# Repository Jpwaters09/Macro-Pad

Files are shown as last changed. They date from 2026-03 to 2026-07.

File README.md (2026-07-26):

# Macro Pad

A 12-key macro pad with a configurable rotary encoder and OLED display, built around the RP2354A microcontroller and custom MicroPython firmware. Fully programmable through a web-based configurator.

##

<div style="display: flex">
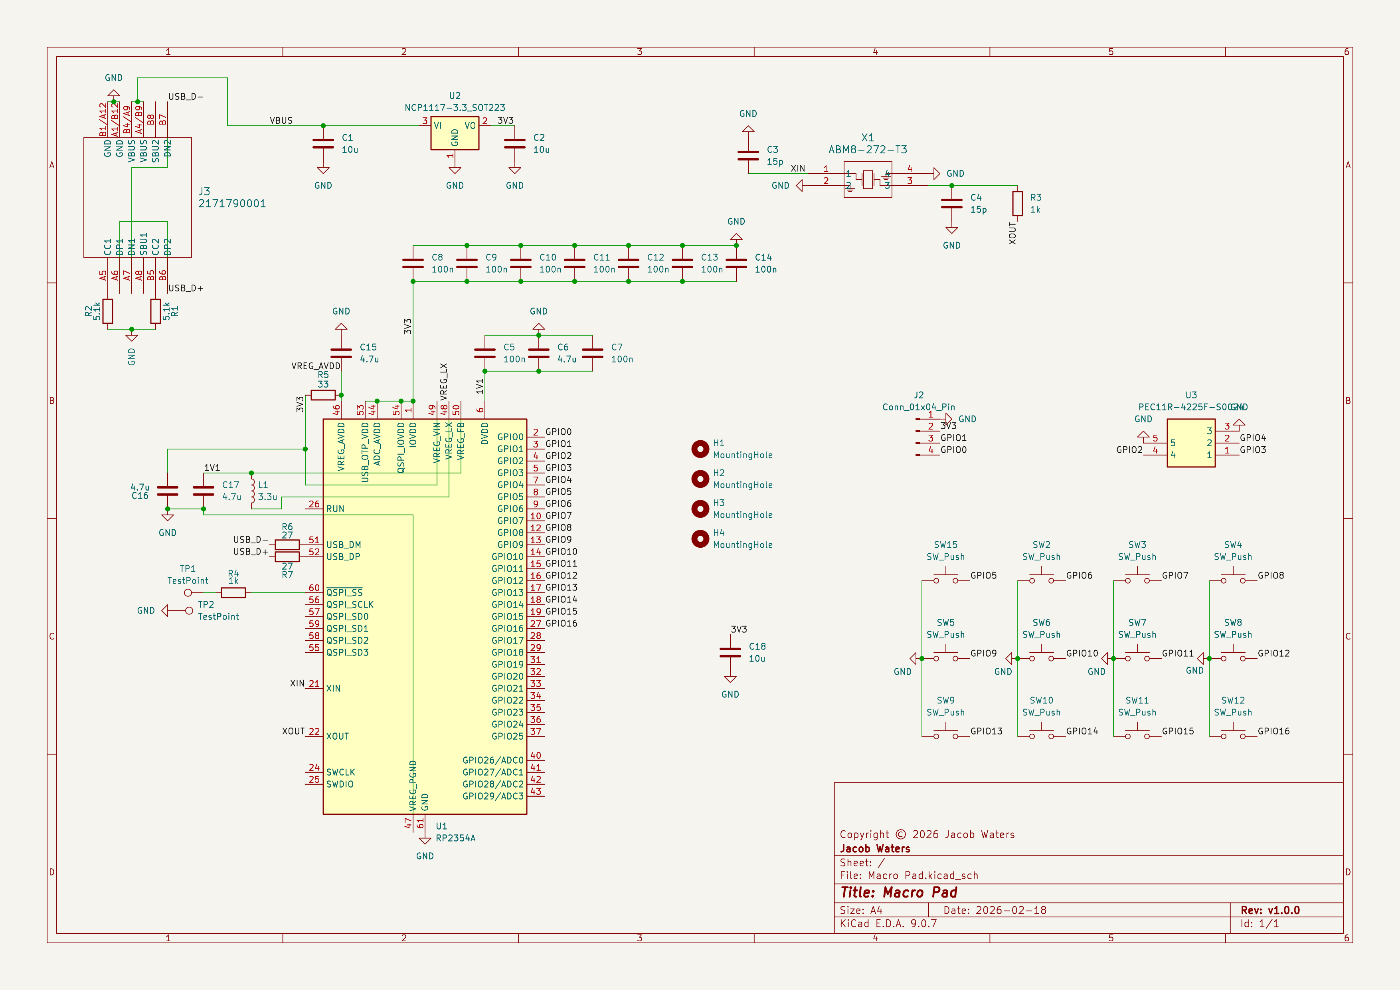
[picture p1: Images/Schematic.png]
  
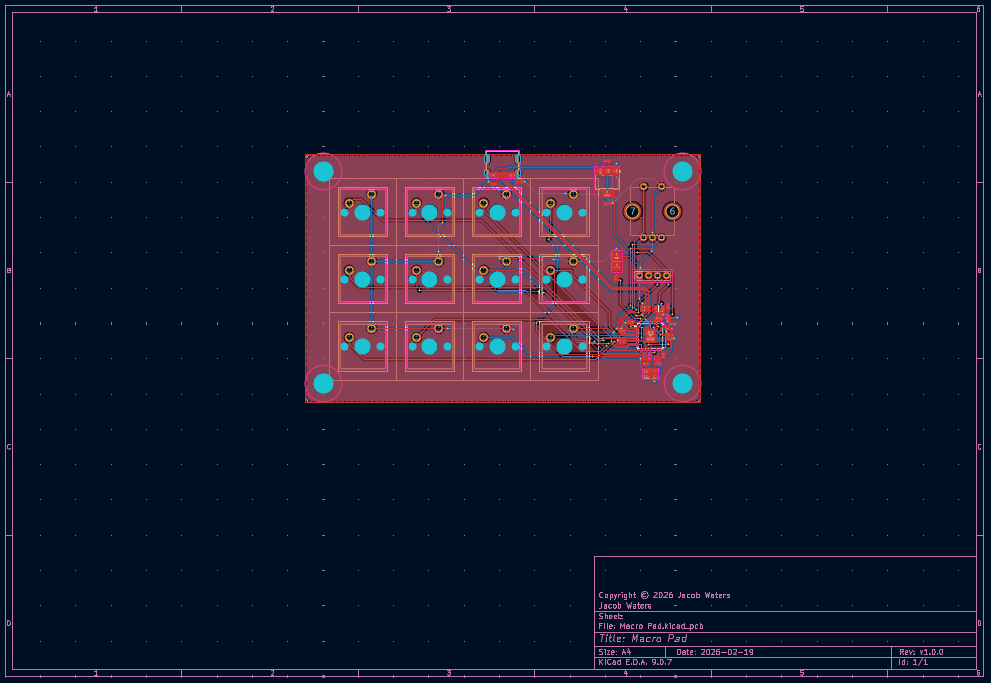
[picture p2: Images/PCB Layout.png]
  
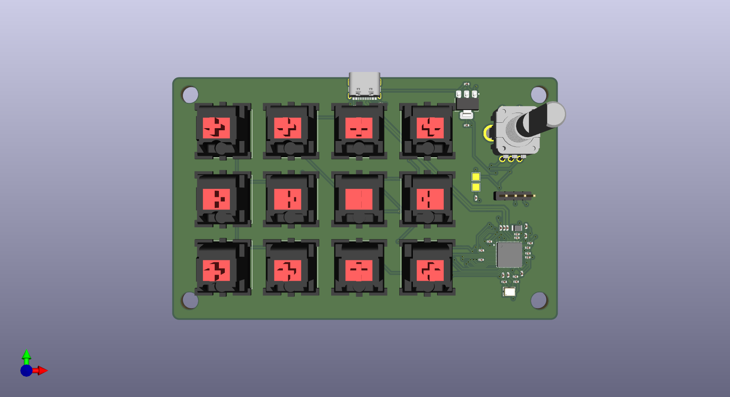
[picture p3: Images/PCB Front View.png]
  
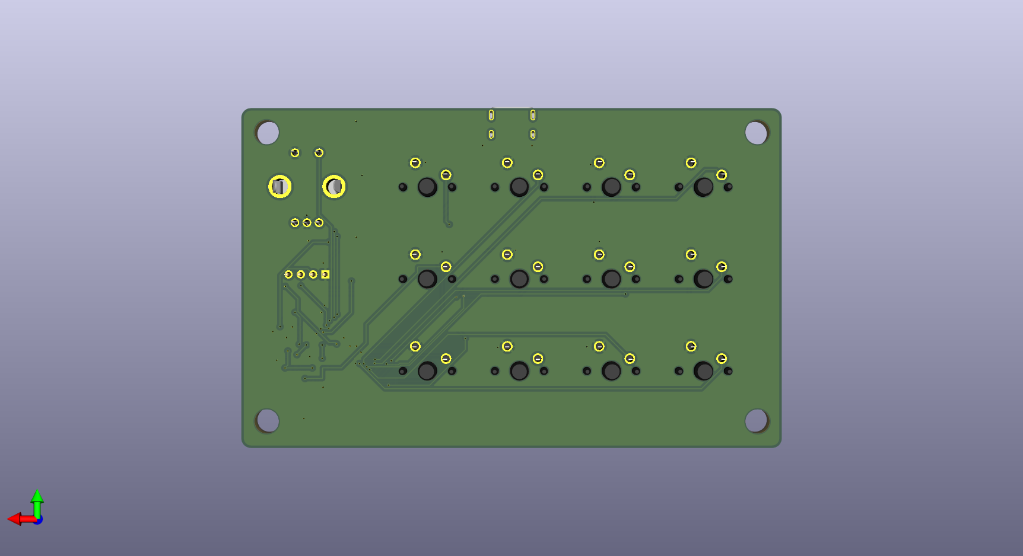
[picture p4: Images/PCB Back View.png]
  
  
  
</div>

##

## How to Use
Plug the Macro Pad into your Windows, Linux, or macOS device using a USB-C data cable, then go to the [Installation Website](https://macropad.jpwaters09.com/Install%20or%20Update) and follow the steps to install (or update) the Macro Pad firmware. This requires a browser that supports Web Serial (Chrome, Edge, Opera, or Firefox), Safari isn't supported.

The OLED display shows the current layer and the function assigned to each key. Press and hold the rotary encoder button to switch layers.

To configure the device (adding, editing, or deleting layers) visit the [Macro Pad Programmer](https://macropad.jpwaters09.com/Configurator).

## Coming Soon
 - A Windows app that will allow you to update and configure settings for the Macro Pad.

## Why I Made This
I built this project to create a fully customisable and open-sourced macro pad. It has also served as a way to develop my skills in schematic design, PCB layout, and 3D Modelling.

## Features
 - USB C
 - 12 macro buttons
 - Rotary encoder with button
 - 128 x 64 OLED display
 - 3D printable housing
 - RP2354A microcontroller
 - 2MB internal flash storage
 - Custom Micropython firmware
 - Multiple programmable layers
 - Web-based configurator (no software install)
 - USB HID compliant (works instantly on any OS)

## Bill Of Materials
|Item |Description |Quantity|Unit Price (£)|Total Price (£) Inc. Tax|URL |
|---|---|---|---|---|---|
|CL05A104KA5NNNC |100nF ±10% 25V Ceramic Capacitor X5R 0402 |100 |$0.0016 |$0.16 |https://www.lcsc.com/product-detail/C100072.html |
|CC0402KRX5R5BB103 |10nF ±10% 6.3V Ceramic Capacitor X5R 0402 |100 |$0.0012 |$0.12 |https://www.lcsc.com/product-detail/C1853984.html |
|HGC0805R7106K250NSLJ  |10uF ±10% 25V Ceramic Capacitor X7R 0805 |5 |$0.1585 |$0.79 |https://www.lcsc.com/product-detail/C33546010.html |
|ABM8-272-T3 |±30ppm 10pF ±30ppm SMD3225-4P Crystals RoHS |5 |$0.2902 |$1.45 |https://www.lcsc.com/product-detail/C20625731.html |
|CL05C150JB5NNNC |15pF ±5% 50V Ceramic Capacitor C0G 0402 |100 |$0.0036 |$0.36 |https://www.lcsc.com/product-detail/C86285.html |
|FRC0402J102 TS |1kΩ 62.5mW 50V Thick Film Resistor ±100ppm/℃ ±5% 0402 Chip Resistor |100 |$0.0008 |$0.08 |https://www.lcsc.com/product-detail/C2906899.html |
|RC0402FR-0727RL |27Ω ±1% 62.5mW 0402 Thick Film Resistor |100 |$0.0008 |$0.08 |https://www.lcsc.com/product-detail/C138021.html |
|AOTA-B201610S3R3-101-T|2.1A 3.3uH 115mΩ 2.4A Molded Inductor 0806 Fixed Inductors RoHS |5 |$0.2888 |$1.44 |https://www.lcsc.com/product-detail/C42411119.html |
|RAT0233R0FTH |62.5mW 33Ω 50V Thick Film Resistor ±100ppm/℃ ±1% 0402 Chip Resistor |100 |$0.0015 |$0.15 |https://www.lcsc.com/product-detail/C5139599.html |
|CL05A475KQ5NRNC |4.7uF ±10% 6.3V Ceramic Capacitor X5R 0402 |100 |$0.0060 |$0.60 |https://www.lcsc.com/product-detail/C2932473.html |
|1RC0402F5101 |5.1kΩ ±1% 62.5mW 0402 Thick Film Resistor |100 |$0.0009 |$0.09 |https://www.lcsc.com/product-detail/C53224182.html |
|NCP1117ST33T3G |Linear Voltage Regulator IC Positive Fixed 1 Output 1A SOT-223 |5 |$0.2615 |$1.31 |https://www.lcsc.com/product-detail/C26537.html |
|PZ254V-11-04P |Pin Header 4 Position 2.54mm Pitch Single Row Through Hole -40℃~+105℃|20 |$0.0236 |$0.47 |https://www.lcsc.com/product-detail/C2691448.html |
|Rotary Encoder Knob |22x12mm 6mm D-Type Shaft Hole Knob |1 |$1.6500 |$1.65 |https://www.aliexpress.com/item/1005011592374989.html|
|SSD1306 |128x64 I2C OLED Display |1 |$0.9900 |$0.99 |https://www.aliexpress.com/item/1005008995931139.html|
|PEC11R-4225F-S0024 |Plugin Encoders RoHS |1 |$1.8539 |$1.85 |https://www.lcsc.com/product-detail/C18198884.html |
|Cherry MX Keycaps |Blank black keycap for Cherry MX switches |20 |$0.1500 |$3.00 |https://www.aliexpress.com/item/1005007572331245.html|
|Cherry MX Red Switch  |Cherry MX red 3-pin linear switches |16 |$0.65 |$10.43 |https://www.aliexpress.com/item/4000100166477.html |
|RP2354A |QFN-60(7x7) Microcontrollers RoHS |1 |$1.4615 |$1.46 |https://www.lcsc.com/product-detail/C41378174.html |
|2171790001 |USB 2.0 5A 1 16P -40℃~+85℃ SMD USB Connector Assemblies RoHS |1 |$0.6229 |$0.62 |https://www.lcsc.com/product-detail/C3197684.html |

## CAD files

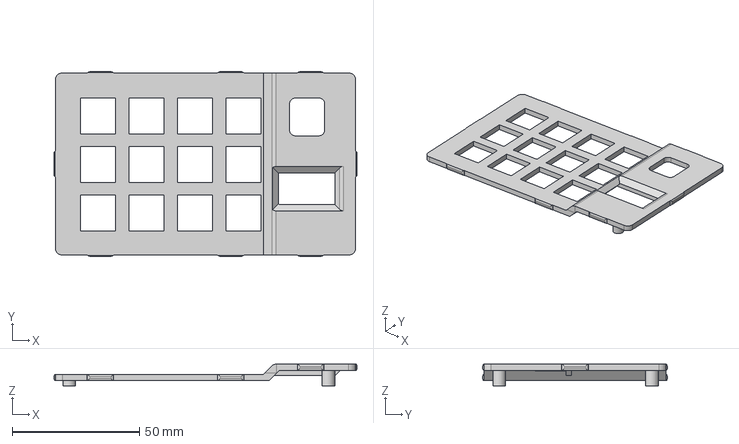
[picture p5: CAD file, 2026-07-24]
CAD Files/Macro Pad Top.step
119.0 x 72.5 x 8.51 mm

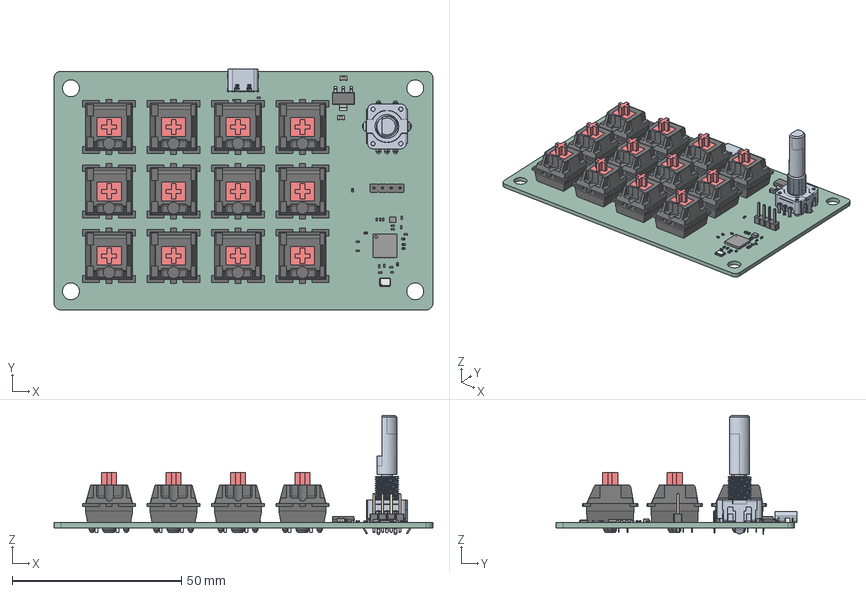
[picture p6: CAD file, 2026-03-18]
PCB Files/Macro Pad.step
112.0 x 71.2 x 35.2 mm
C_0402_1005Metric x 23
C_0805_2012Metric x 2
ThermalPin
PinsArrayLR
PinsArrayTB
SOT-223
PinHeader_1x04_P2.54mm_Vertical
ABM8-272-T3
PEC11R-4225F-S0024
AOTA-B201610S3R3-101-T
Macro Pad_PCB

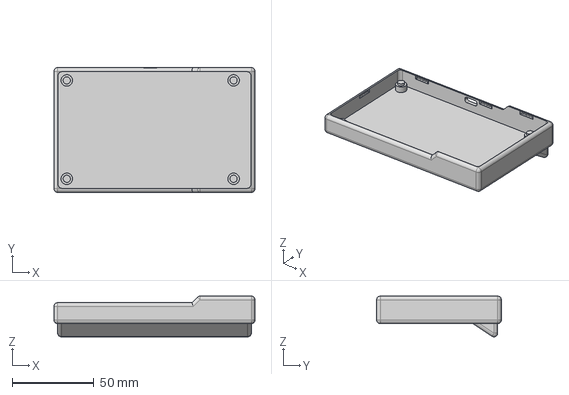
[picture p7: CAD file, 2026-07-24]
CAD Files/Macro Pad Bottom.step
122.6 x 76.1 x 24.9 mm

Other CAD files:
CAD Files/Macro Pad Bottom.stl
CAD Files/Macro Pad Top.stl
CAD Files/Macro Pad.f3z

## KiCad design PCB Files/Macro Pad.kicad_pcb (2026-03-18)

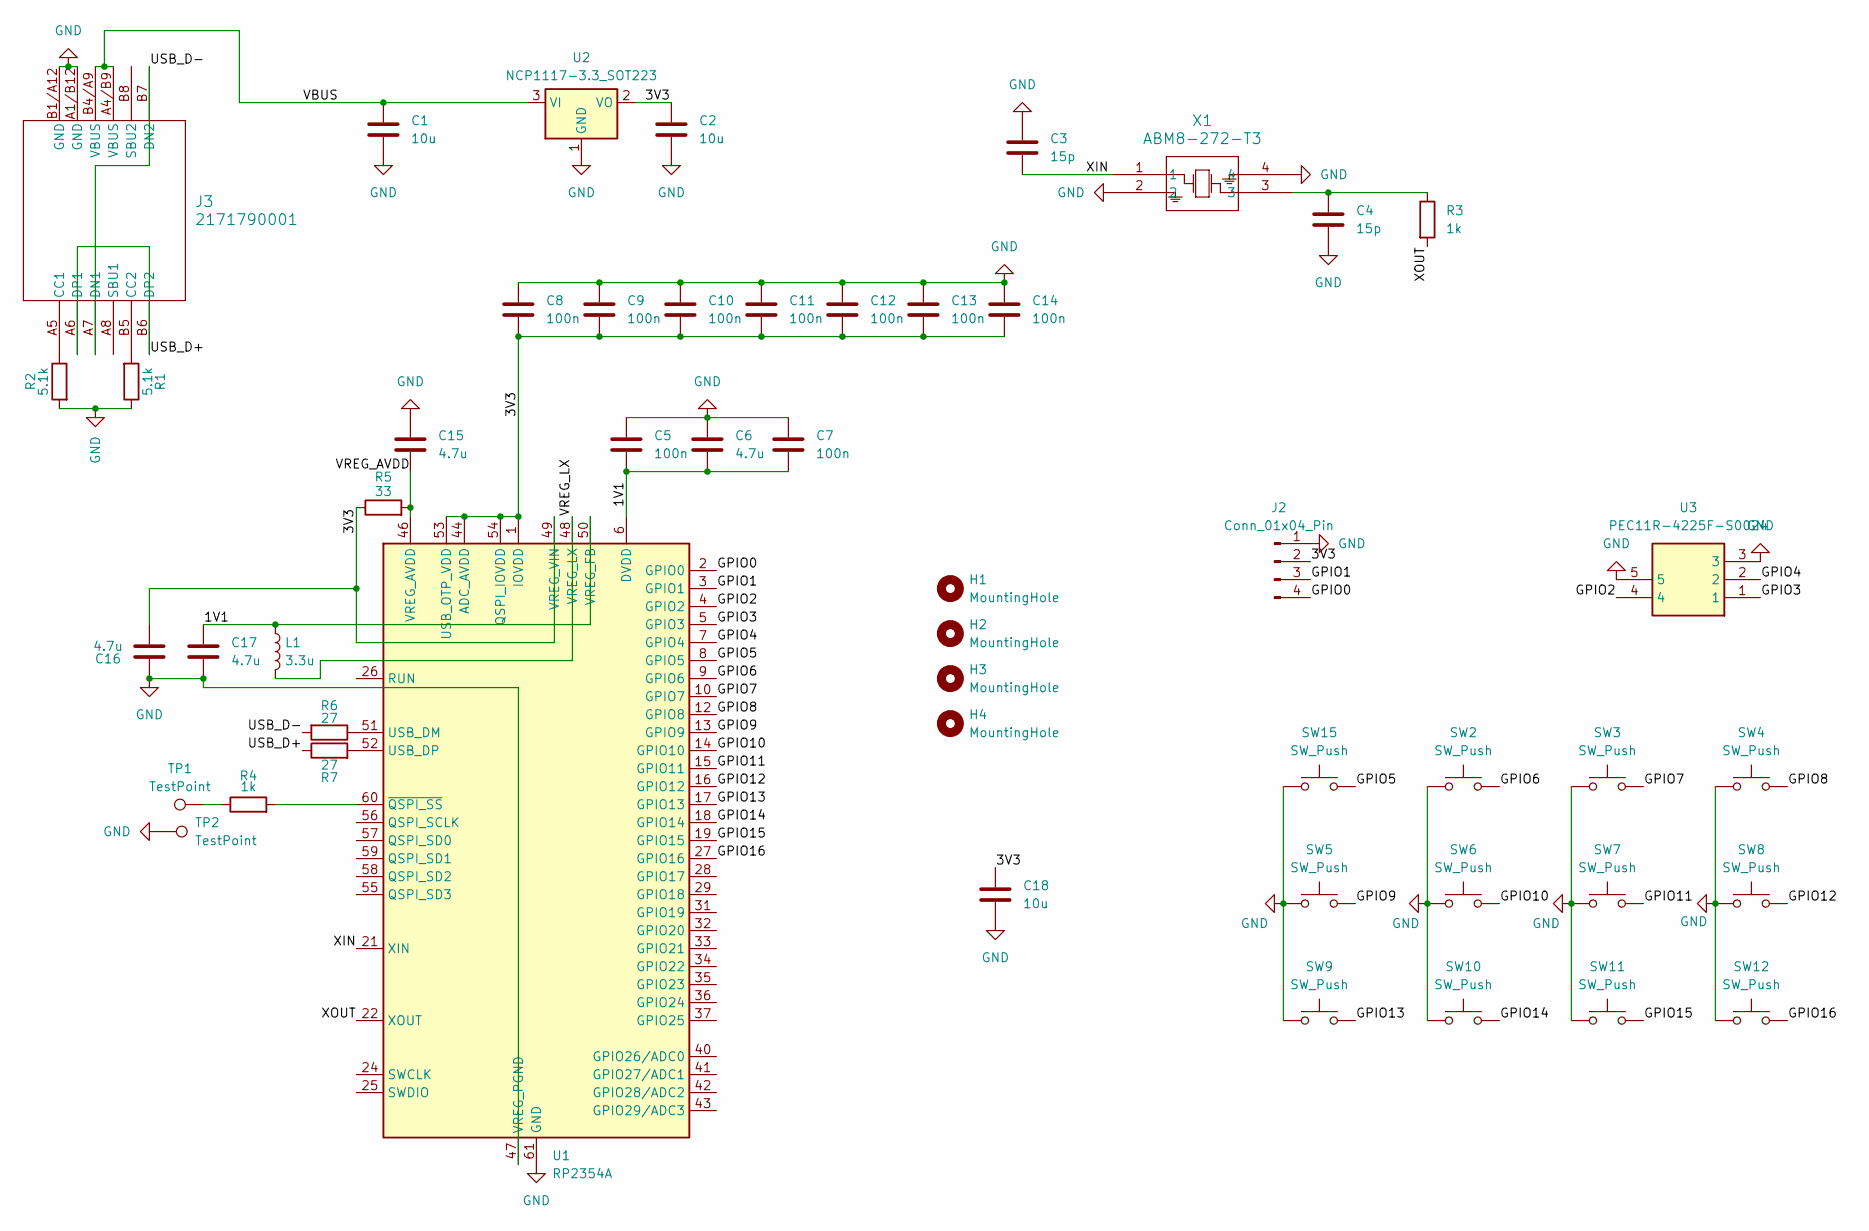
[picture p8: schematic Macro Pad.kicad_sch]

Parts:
C1, C2: 10u; C_0805_2012Metric
C3, C4: 15p; C_0402_1005Metric
C5, C7, C8, C9, C10, C11, C12, C13, C14: 100n; C_0402_1005Metric
C6, C15, C16, C17: 4.7u; C_0402_1005Metric
C18: 10u; C_0402_1005Metric
H1, H2, H3, H4: MountingHole; MountingHole_5mm
J2: Conn_01x04_Pin; PinHeader_1x04_P2.54mm_Vertical
J3: 2171790001; 2171790001_MOL
L1: 3.3u; AOTAB201610S3R3101T
R1, R2: 5.1k; C_0402_1005Metric
R3, R4: 1k; C_0402_1005Metric
R5: 33; C_0402_1005Metric
R6, R7: 27; C_0402_1005Metric
SW2, SW3, SW4, SW5, SW6, SW7, SW8, SW9, SW10, SW11, SW12, SW15: SW_Push; SW_Cherry_MX_1.00u_PCB
TP1, TP2: TestPoint; TestPoint_Pad_2.0x2.0mm
U1: RP2354A; QFN-60-1EP_7x7mm_P0.4mm_EP3.4x3.4mm
U2: NCP1117-3.3_SOT223; SOT-223-3_TabPin2
U3: PEC11R-4225F-S0024; Manufacturer_Part_Number PEC11R-4225F-S0024; Mouser Part Number 652-PEC11R-4225F-S24
X1: ABM8-272-T3; ABM8-272-T3_ABR

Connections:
/1V1: C5.2, C6.2, C7.2, C17.1, L1.1, U1.6 (DVDD), U1.23 (DVDD), U1.39 (DVDD), U1.50 (VREG_FB)
/3V3: C2.1, C8.2, C9.2, C10.2, C11.2, C12.2, C13.2, C14.2, C16.2, C18.1, J2.2, R5.1, U1.1 (IOVDD), U1.11 (IOVDD), U1.20 (IOVDD), U1.30 (IOVDD), U1.38 (IOVDD), U1.44 (ADC_AVDD), U1.45 (IOVDD), U1.49 (VREG_VIN), U1.53 (USB_OTP_VDD), U1.54 (QSPI_IOVDD), U2.2 (VO)
/GPIO0: J2.4, U1.2 (GPIO0)
/GPIO1: J2.3, U1.3 (GPIO1)
/GPIO2: U1.4 (GPIO2), U3.4
/GPIO3: U1.5 (GPIO3), U3.1
/GPIO4: U1.7 (GPIO4), U3.2
/GPIO5: SW15.2, U1.8 (GPIO5)
/GPIO6: SW2.2, U1.9 (GPIO6)
/GPIO7: SW3.2, U1.10 (GPIO7)
/GPIO8: SW4.2, U1.12 (GPIO8)
/GPIO9: SW5.2, U1.13 (GPIO9)
/GPIO10: SW6.2, U1.14 (GPIO10)
/GPIO11: SW7.2, U1.15 (GPIO11)
/GPIO12: SW8.2, U1.16 (GPIO12)
/GPIO13: SW9.2, U1.17 (GPIO13)
/GPIO14: SW10.2, U1.18 (GPIO14)
/GPIO15: SW11.2, U1.19 (GPIO15)
/GPIO16: SW12.2, U1.27 (GPIO16)
/USB_D+: J3.A6 (DP1), J3.B6 (DP2), R7.1
/USB_D-: J3.A7 (DN1), J3.B7 (DN2), R6.2
/VBUS: C1.1, J3.A4/B9 (VBUS), J3.B4/A9 (VBUS), U2.3 (VI)
/VREG_AVDD: C15.2, R5.2, U1.46 (VREG_AVDD)
/VREG_LX: L1.2, U1.48 (VREG_LX)
/XIN: C3.1, U1.21 (XIN), X1.1
/XOUT: R3.2, U1.22 (XOUT)
GND: C1.2, C2.2, C3.2, C4.2, C5.1, C6.1, C7.1, C8.1, C9.1, C10.1, C11.1, C12.1, C13.1, C14.1, C15.1, C16.1, C17.2, C18.2, J2.1, J3.A1/B12 (GND), J3.B1/A12 (GND), R1.1, R2.2, SW2.1, SW3.1, SW4.1, SW5.1, SW6.1, SW7.1, SW8.1, SW9.1, SW10.1, SW11.1, SW12.1, SW15.1, TP2.1, U1.47 (VREG_PGND), U1.61 (GND), U2.1 (GND), U3.3, U3.5, X1.2, X1.4
unnamed: C4.1, R3.1, X1.3
unnamed: J3.A5 (CC1), R2.1
unnamed: J3.B5 (CC2), R1.2
unnamed: R4.1, TP1.1
unnamed: R6.1, U1.51 (USB_DM)
unnamed: R7.2, U1.52 (USB_DP)
unnamed: R4.2, U1.60 (~QSPI_SS)

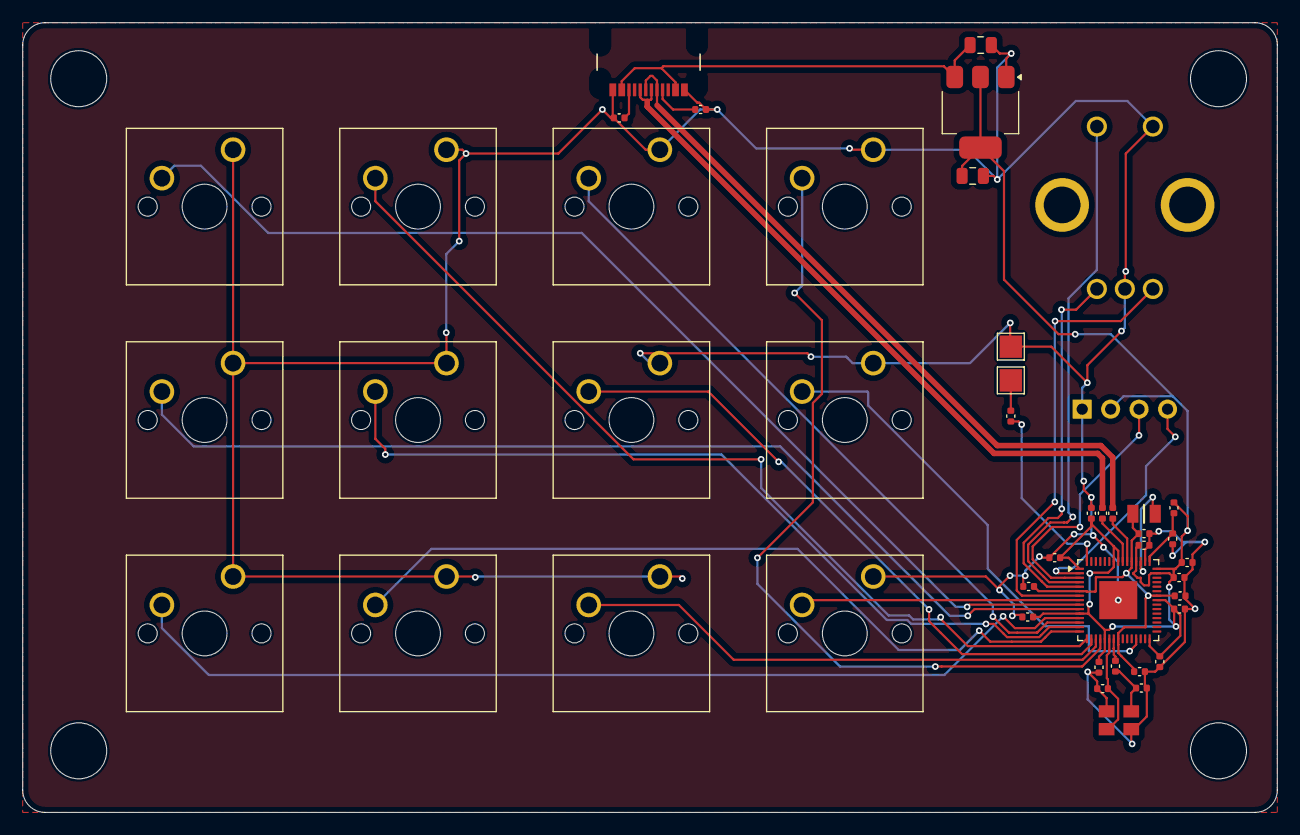
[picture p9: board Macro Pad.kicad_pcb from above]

Board: 2 copper layers, 112.0 x 70.5 mm, 50 parts (0 on the bottom side), 34 nets.

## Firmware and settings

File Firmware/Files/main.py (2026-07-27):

from machine import Pin, I2C
import ssd1306
from time import sleep
import time
from screens import *
from displayFunctions import *
import usb.device
from usb.device.keyboard import KeyboardInterface
from usb.device.mouse import MouseInterface
import _thread
from consumer import ConsumerInterface
import json
import sys
import os

with open("config.json", "r") as file:
    data = json.load(file)

    activated = data["Activated"]

    serialNumber = data["Serial Number"]

    softwareVersion = data["Software Version"]
    
    sleepTime = data["Sleep Time"]

hardwareVersionMajor, hardwareVersionMinor, hardwareVersionMicro = map(int, "v1.0.0".lstrip("v").split("."))
hardwareVersionBcd = (hardwareVersionMajor << 8) | (hardwareVersionMinor << 4) | hardwareVersionMicro

keyboard = KeyboardInterface()
mouse = MouseInterface()
consumer = ConsumerInterface()

i2c = I2C(sda=Pin("OLED_SDA"), scl=Pin("OLED_SCL"))
display = ssd1306.SSD1306_I2C(128, 64, i2c)

macroButtonPins = ["ENCODER_BTN",
                   "BTN_1", "BTN_2", "BTN_3", "BTN_4",
                   "BTN_5", "BTN_6", "BTN_7", "BTN_8",
                   "BTN_9", "BTN_10", "BTN_11", "BTN_12"]

macroButtons = []

for pin in macroButtonPins:
    macroButtons.append(Pin(pin, Pin.IN, Pin.PULL_UP))

display.contrast(0)

if activated or serialNumber:
    usb.device.get().init(keyboard,
                          consumer,
                          mouse,
                          builtin_driver=True,
                          manufacturer_str="Jacob Waters",
                          product_str="Macro Pad",
                          serial_str=serialNumber,
                          id_vendor=4617,
                          id_product=31291,
                          bcd_device=hardwareVersionBcd)

startUpScreen(display, softwareVersion)
increaseBrightness(display, speed=0.02)

if not activated or not serialNumber:
    notActivatedScreen(display)
    
    while True:
        pass

layers = len(os.listdir("/Layers"))

if layers == 0:
    noLayersScreen(display)
    
    while True:
        pass

loadedLayers = {}

for layer in range(1, layers + 1):
    sys.path.append(f"/Layers/{layer}/")
    layerMod = __import__(f"Layer{layer}")
    keysMod = __import__(f"Keys{layer}")
    
    loadedLayers[layer] = {
        "layer": layerMod,
        "keys": keysMod,
    }

currentLayer = 1

display.fill(0)

loadedLayers[currentLayer]["layer"].layer(display)

last_press = time.ticks_ms()
lock = _thread.allocate_lock()
displayBrightnessLowered = False
displaySleep = False

R_START     = 0x0
R_CW_FINAL  = 0x1
R_CW_BEGIN  = 0x2
R_CW_NEXT   = 0x3
R_CCW_BEGIN = 0x4
R_CCW_FINAL = 0x5
R_CCW_NEXT  = 0x6

DIR_CW  = 0x10
DIR_CCW = 0x20

ttable = (
    (R_START,    R_CW_BEGIN,  R_CCW_BEGIN, R_START),
    (R_CW_NEXT,  R_START,     R_CW_FINAL,  R_START | DIR_CW),
    (R_CW_NEXT,  R_CW_BEGIN,  R_START,     R_START),
    (R_CW_NEXT,  R_CW_BEGIN,  R_CW_FINAL,  R_START),
    (R_CCW_NEXT, R_START,     R_CCW_BEGIN, R_START),
    (R_CCW_NEXT, R_CCW_FINAL, R_START,     R_START | DIR_CCW),
    (R_CCW_NEXT, R_CCW_FINAL, R_CCW_BEGIN, R_START),
)

encoderA = Pin("ENCODER_A", Pin.IN, Pin.PULL_UP)
encoderB = Pin("ENCODER_B", Pin.IN, Pin.PULL_UP)

encoder_state   = R_START
encoder_delta   = 0
encoder_velocity = 0.0
last_encoder_ms = time.ticks_ms()

def encoder_handler(pin):
    global encoder_state, encoder_delta, last_press

    pinstate = (encoderA.value() << 1) | encoderB.value()
    encoder_state = ttable[encoder_state & 0x0F][pinstate]
    direction = encoder_state & 0x30

    if direction == DIR_CW:
        encoder_delta += 1
        
    elif direction == DIR_CCW:
        encoder_delta -= 1

    if direction:
        with lock:
            last_press = time.ticks_ms()

encoderA.irq(trigger=Pin.IRQ_FALLING | Pin.IRQ_RISING, handler=encoder_handler)
encoderB.irq(trigger=Pin.IRQ_FALLING | Pin.IRQ_RISING, handler=encoder_handler)

stopIdleWatcher = False

def idleWatcher():
    global last_press, displayBrightnessLowered, displaySleep

    while not stopIdleWatcher:
        with lock:
            elapsed = time.ticks_diff(time.ticks_ms(), last_press)

        if elapsed >= sleepTime:
            if not displayBrightnessLowered:
                decreaseBrightness(display)
                displayBrightnessLowered = True

            elif not displaySleep:
                display.poweroff()
                displaySleep = True

            with lock:
                last_press = time.ticks_ms()
                
        time.sleep_ms(500)
        
def encoderLongPress():
    global currentLayer
    
    if layers > 1:        
        if currentLayer != layers:
            currentLayer += 1
            display.fill(0)
            loadedLayers[currentLayer]["layer"].layer(display)
            
        else:
            currentLayer = 1
            display.fill(0)
            loadedLayers[currentLayer]["layer"].layer(display)
            
_thread.start_new_thread(idleWatcher, ())

prev = [not btn.value() for btn in macroButtons]

pressStartTimes = [None] * len(macroButtons)
nextRepeatTime  = [None] * len(macroButtons)

encoderPressStart = None
encoderLongPressFired = False
encoder_last_dir = 0
encoder_dir_lock_until = 0

while True:
    now = time.ticks_ms()
    dt = time.ticks_diff(now, last_encoder_ms) / 1000.0
    last_encoder_ms = now

    encoder_velocity *= max(0.0, 1.0 - (dt * 7.5))

    if encoder_delta != 0:
        raw = encoder_delta
        encoder_delta = 0

        current_dir = 1 if raw > 0 else -1
        if current_dir != encoder_last_dir and time.ticks_diff(now, encoder_dir_lock_until) < 0:
            raw = 0
            
        else:
            encoder_last_dir = current_dir
            
            if abs(encoder_velocity) > 3.0:
                encoder_dir_lock_until = time.ticks_add(now, 40)

        if raw != 0:
            encoder_velocity += raw * 1.2

            if encoder_velocity > 10:
                encoder_velocity = 10.0
            elif encoder_velocity < -10:
                encoder_velocity = -10.0

    steps = int(round(encoder_velocity))

    if abs(steps) >= 2 and abs(encoder_velocity) < 1.7:
        steps = 1 if encoder_velocity > 0 else -1

    if steps != 0:
        encoder_velocity *= 0.55

        if displaySleep:
            displaySleep = False
            displayBrightnessLowered = False
            display.poweron()
            increaseBrightness(display)
            
        elif displayBrightnessLowered:
            displayBrightnessLowered = False
            increaseBrightness(display)
            
        loadedLayers[currentLayer]["keys"].rotaryChecker(keyboard, consumer, mouse, steps)

    for i, btn in enumerate(macroButtons):
        pressed = not btn.value()
        
        if i == 0:
            if pressed and not prev[i]:
                encoderPressStart = time.ticks_ms()
                encoderLongPressFired = False

                if displaySleep:
                    displaySleep = False
                    displayBrightnessLowered = False
                    display.poweron()
                    increaseBrightness(display)
                    
                elif displayBrightnessLowered:
                    displayBrightnessLowered = False
                    increaseBrightness(display)

                with lock:
                    last_press = time.ticks_ms()

            elif pressed and prev[i] and not encoderLongPressFired:
                if encoderPressStart is not None and time.ticks_diff(time.ticks_ms(), encoderPressStart) >= 500:
                    encoderLongPressFired = True
                    encoderLongPress()

            elif not pressed and prev[i]:
                if not encoderLongPressFired:
                    loadedLayers[currentLayer]["keys"].keyChecker(keyboard, consumer, mouse, 0)

            prev[i] = pressed
            
        else:
            if pressed != prev[i]:
                if pressed:
                    loadedLayers[currentLayer]["keys"].keyChecker(keyboard, consumer, mouse, i)

                    pressStartTimes[i] = time.ticks_ms()
                    nextRepeatTime[i] = time.ticks_add(pressStartTimes[i], 500)

                    if displaySleep:
                        displaySleep = False
                        displayBrightnessLowered = False
                        display.poweron()
                        increaseBrightness(display)

                    elif displayBrightnessLowered:
                        displayBrightnessLowered = False
                        increaseBrightness(display)

                    with lock:
                        last_press = time.ticks_ms()

                else:
                    pressStartTimes[i] = None
                    nextRepeatTime[i] = None

                prev[i] = pressed

            elif pressed and nextRepeatTime[i] is not None:
                now = time.ticks_ms()
                if time.ticks_diff(now, nextRepeatTime[i]) >= 0:
                    loadedLayers[currentLayer]["keys"].keyChecker(keyboard, consumer, mouse, i)
                    nextRepeatTime[i] = time.ticks_add(now, 30)

                    with lock:
                        last_press = now

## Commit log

2026-03-18 Update Macro Pad BOM with new item entries
    [Macro Pad BOM.csv]
2026-03-18 Update Macro Pad BOM.csv
    [Macro Pad BOM.csv]
2026-03-18 Add Bill of Materials to README
    Added a Bill of Materials section with detailed item descriptions, quantities, prices, and URLs for sourcing components.
2026-03-19 Update Macro Pad BOM with additional components
    [Macro Pad BOM.csv]
2026-03-22 Update resistor details in README.md
2026-03-22 Fix resistor power rating in README
2026-03-22 Update Macro Pad BOM with new items
    [Macro Pad BOM.csv]
2026-03-26 Revise Bill of Materials with updated pricing
    Updated the Bill of Materials section with new item prices and URLs.
2026-04-02 Revise Bill Of Materials with new items
    Updated Bill Of Materials with new components and prices.
2026-06-22 Update quantity for Cherry MX Red Switch in README
2026-06-22 Revise Macro Pad BOM with updated component details
    Updated quantities and URLs for several components.
    [Macro Pad BOM.csv]
2026-06-22 Modify Cherry MX Red Switch details in README
    Updated the quantity and price for Cherry MX Red Switch.
2026-06-22 Update Macro Pad BOM with new item formatting
    [Macro Pad BOM.csv]
2026-10-29 Doubled default sleep time (from 120000ms to 240000ms) and improved encoder logic by adding acceleration and making it smoother

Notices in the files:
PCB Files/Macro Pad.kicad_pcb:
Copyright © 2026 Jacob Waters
